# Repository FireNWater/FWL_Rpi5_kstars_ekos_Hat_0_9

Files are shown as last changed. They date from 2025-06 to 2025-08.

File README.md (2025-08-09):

# Raspberry Pi Hat for AstroArch Version 0.9

This repository is for a Raspberry Pi Hat that provides various hardware control functions for Astrophotography equipment. 

Currently this repository only contains the KiCAD files, but I will add more photos and instructions to build your own as I progress.

Here is the link to order PCBs at OshPark:  https://oshpark.com/shared_projects/S5zMuqNM

This is the link to DigiKey Parts List: https://www.digikey.com/en/mylists/list/DTLNYIF8ZV

The DigiKey list includes 10% attrition, so depending on how good you think you are you can save a bit of money there.

The files in the "Linux Software" folder are system files and aliases to help you control the various functions of the hat.  The systemd files are written so that all of the DC power ports and Dew Heater ports turn on once the Raspberry Pi has completed its boot up.  The udev rules will allow you to control the Rpi GPIO ports from the terminal without using sudo.  The aliases, are shortcuts to turning the DC power ports and Dew Heaters on and off from a terminal.

The "libgpiod" package must be installed in order to control the GPIO pins from the command line.  To install in Arch Linux type: "sudo pacman -S libgpiod" at the command line.

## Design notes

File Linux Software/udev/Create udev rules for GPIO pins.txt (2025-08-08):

https://wiki.gentoo.org/wiki/User:Brushdemon/Raspberry_Pi_GPIO

https://github.com/RPi-Distro/raspberrypi-sys-mods/blob/bookworm/etc.armhf/udev/rules.d/99-com.rules

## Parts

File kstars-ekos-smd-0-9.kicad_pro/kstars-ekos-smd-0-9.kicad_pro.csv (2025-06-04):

Reference | Value | Datasheet | Footprint | Qty | DNP
C1 | 10uF | ~ | Capacitor_SMD:C_0805_2012Metric | 1
C2,C2-1,C2-2 | 22uF | ~ | Capacitor_SMD:C_0805_2012Metric | 3
C3 | 100nF | ~ | Capacitor_SMD:C_0805_2012Metric | 1
C4 | 100pF | ~ | Capacitor_SMD:C_0805_2012Metric | 1
C5 | 2.7nF | ~ | Capacitor_SMD:C_0805_2012Metric | 1
C6 | 33pF | ~ | Capacitor_SMD:C_0805_2012Metric | 1
C11,C12,C13,C14,C15,C16 | ~ |  | Anderson Power Pole:APP 45A Vertical Contact | 6
Css1 | 10nF | ~ | Capacitor_SMD:C_0805_2012Metric | 1
F1 | Polyfuse - 6A | ~ | Fuse:Fuse_2920_7451Metric | 1
J1 | Raspberry_Pi_2_3 | https://www.raspberrypi.org/documentation/hardware/raspberrypi/schematics/rpi_SCH_3bplus_1p0_reduced.pdf | Raspberry Pi Hat Parts:Raspberry_Pi_40_Pin_Header_With_Lands | 1
J2,J3 | Conn_01x04 | ~ | Connector_PinHeader_2.54mm:PinHeader_1x04_P2.54mm_Vertical | 2
L1 | 3.6uH |  | 4:THMC0503SP-4R7MG-D | 1
R1 | 115K | ~ | Resistor_SMD:R_0805_2012Metric | 1
R2 | 22.1K | ~ | Resistor_SMD:R_0805_2012Metric | 1
R3 | 560 Ohm | EXB-2HV100JV | Resistor Array:RES_EXB2HV | 1
R5 | 15.8K | ~ | Resistor_SMD:R_0805_2012Metric | 1
U1 | AP64501SP-13 | AP64501QSP-13 | AP64501QSP_13:SO-8EP_DIO | 1
U2,U3,U4,U5 | TLP3553ATP1_F | TLP3553ATP1_F | 4A Solid State Relay:SOIC_3553ATP1_F_TOS | 4
U6,U7 | TLP241ATP1_F | TLP241ATP1_F | 4A Solid State Relay:SOIC_3553ATP1_F_TOS | 2

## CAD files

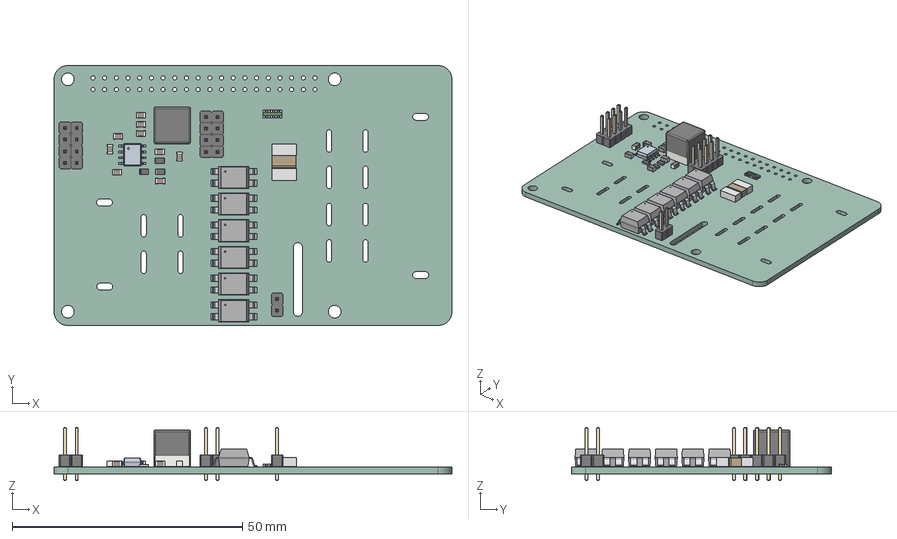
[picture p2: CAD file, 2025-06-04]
kstars-ekos-smd-0-9.kicad_pro/kstars-ekos-smd-0-9.kicad_pro.step
86.5 x 56.5 x 11.5 mm
741X163_CTS
PinHeader_1x02_P2.54mm_Vertical x 5
C_0805_2012Metric x 9
SOIC_3553A_TP1_F_TOS x 12
R_0805_2012Metric x 3
PinHeader_1x04_P2.54mm_Vertical x 2
L_Cenker_CKCS8080
FUSE_2920L11060_LTF
kstars-ekos-smd-0-9.kicad_pro 1.30.1
kstars-ekos-smd-0-9.kicad_pro_PCB

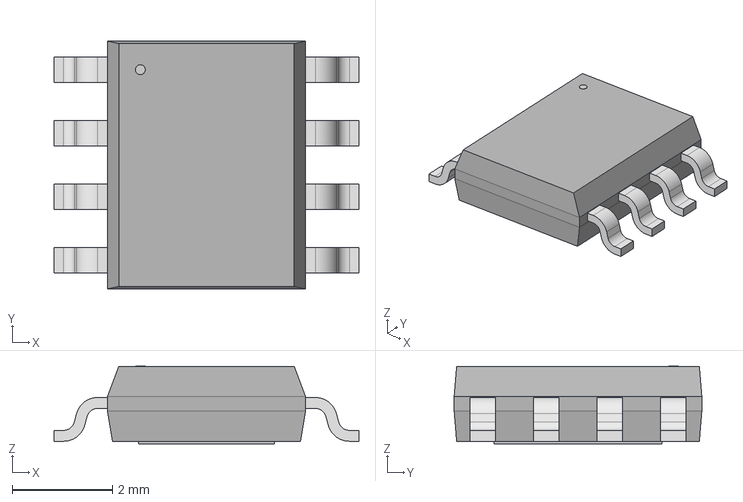
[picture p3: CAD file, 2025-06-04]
kstars-ekos-smd-0-9.kicad_pro/Project Library/AP64501-5V-DC-Buck/AP64501QSP_13/SO-8EP_DIO.step
6.10 x 4.95 x 1.55 mm

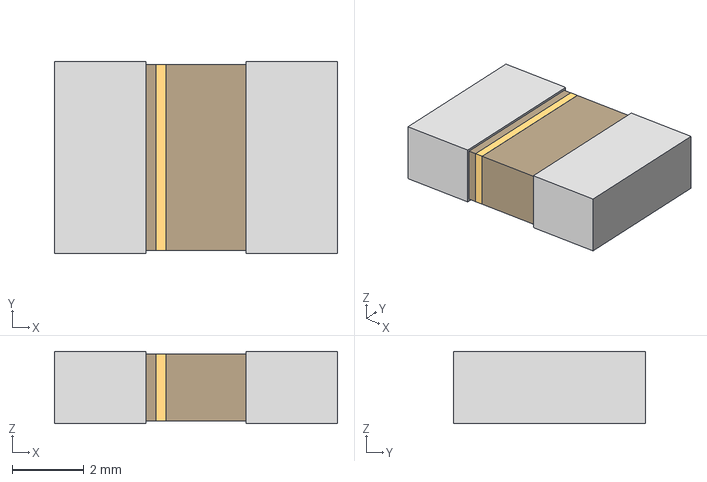
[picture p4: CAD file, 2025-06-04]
kstars-ekos-smd-0-9.kicad_pro/Project Library/PTC Resettable Fuse/ul_2920L110-60MR/FUSE_2920L11060_LTF.step
7.87 x 5.33 x 2.01 mm

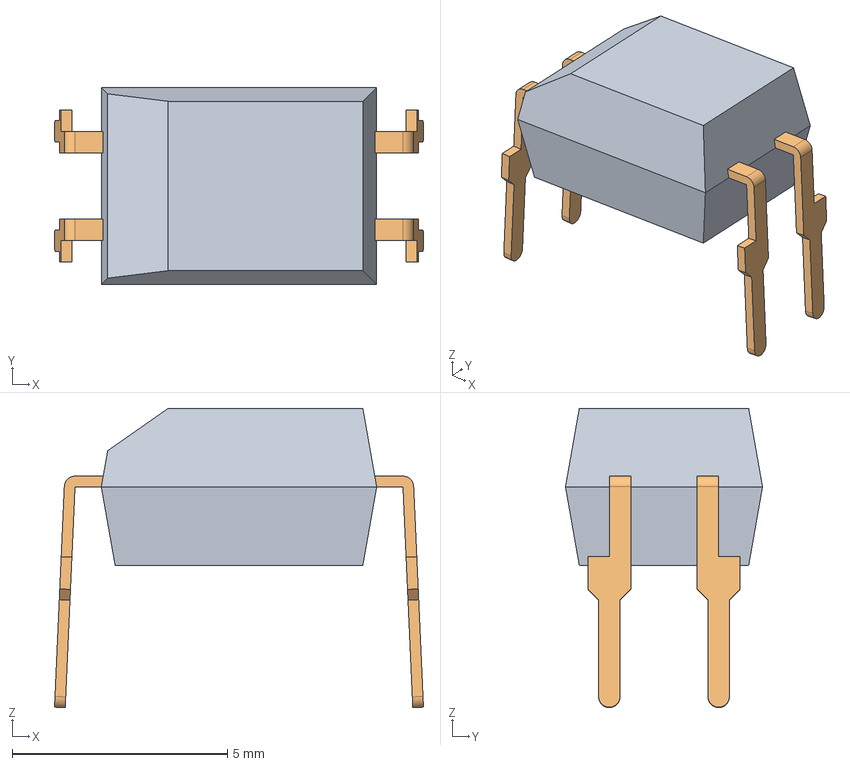
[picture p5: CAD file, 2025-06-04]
kstars-ekos-smd-0-9.kicad_pro/Project Library/TLP241A_TP1_F - 2A Solid State Relay/TLP241A_TP1_F/DIP4_90deg.stp
8.57 x 4.58 x 6.96 mm

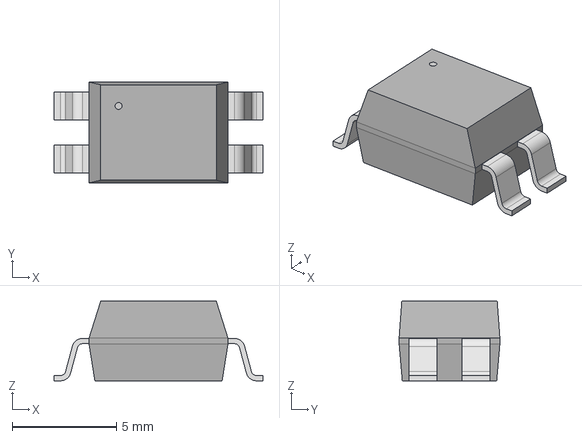
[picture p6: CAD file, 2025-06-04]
kstars-ekos-smd-0-9.kicad_pro/Project Library/TLP3553A_TP1_F - 4A Solid State Relay/TLP3553A_TP1_F/SOIC_3553A_TP1_F_TOS.step
10.0 x 4.83 x 3.81 mm

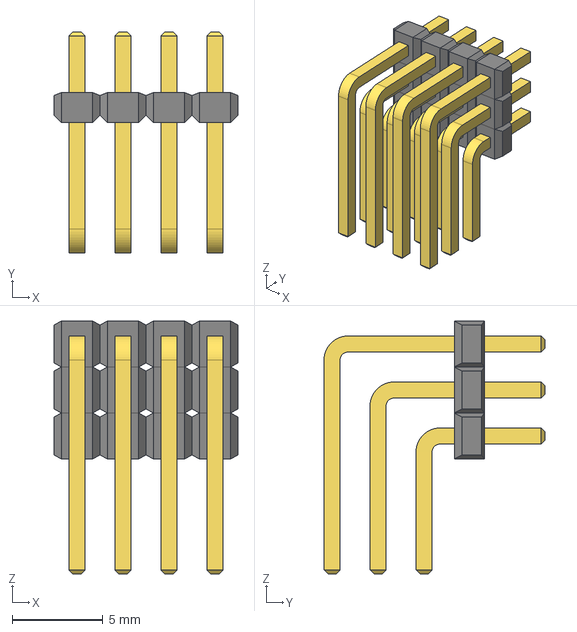
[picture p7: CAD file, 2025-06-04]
kstars-ekos-smd-0-9.kicad_pro/Project Library/TSW_104_08_G_T_RA/KiCADv6/TSW-104-08-T-T-RA_SAI.step
10.2 x 12.2 x 14.0 mm

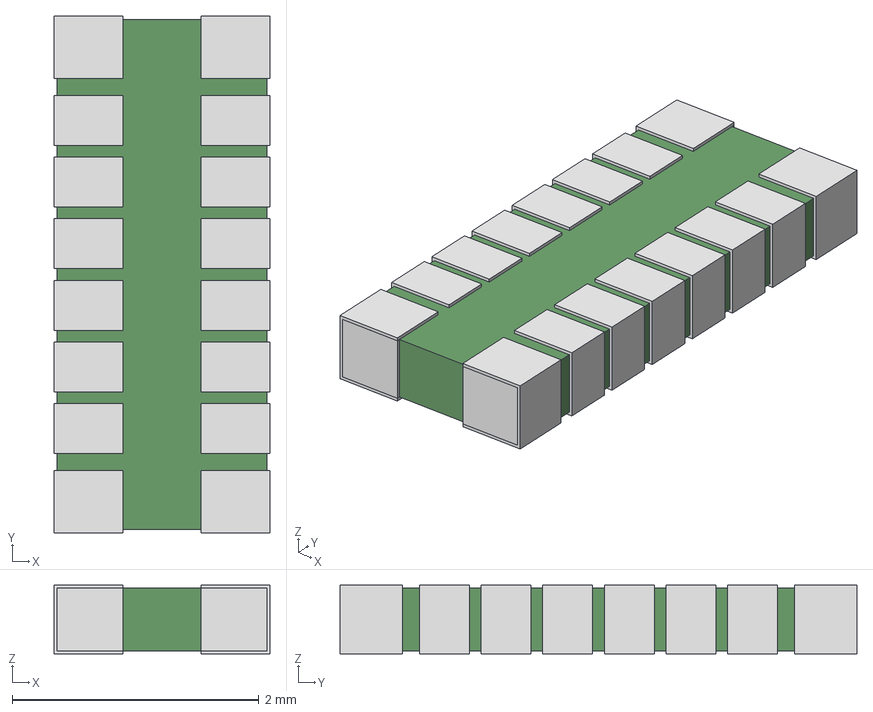
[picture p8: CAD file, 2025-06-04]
kstars-ekos-smd-0-9.kicad_pro/Project Library/ul_EXB-2HV100JV - Resistor Array/ul_741X163102JP/741X163_CTS.step
1.75 x 4.19 x 0.559 mm

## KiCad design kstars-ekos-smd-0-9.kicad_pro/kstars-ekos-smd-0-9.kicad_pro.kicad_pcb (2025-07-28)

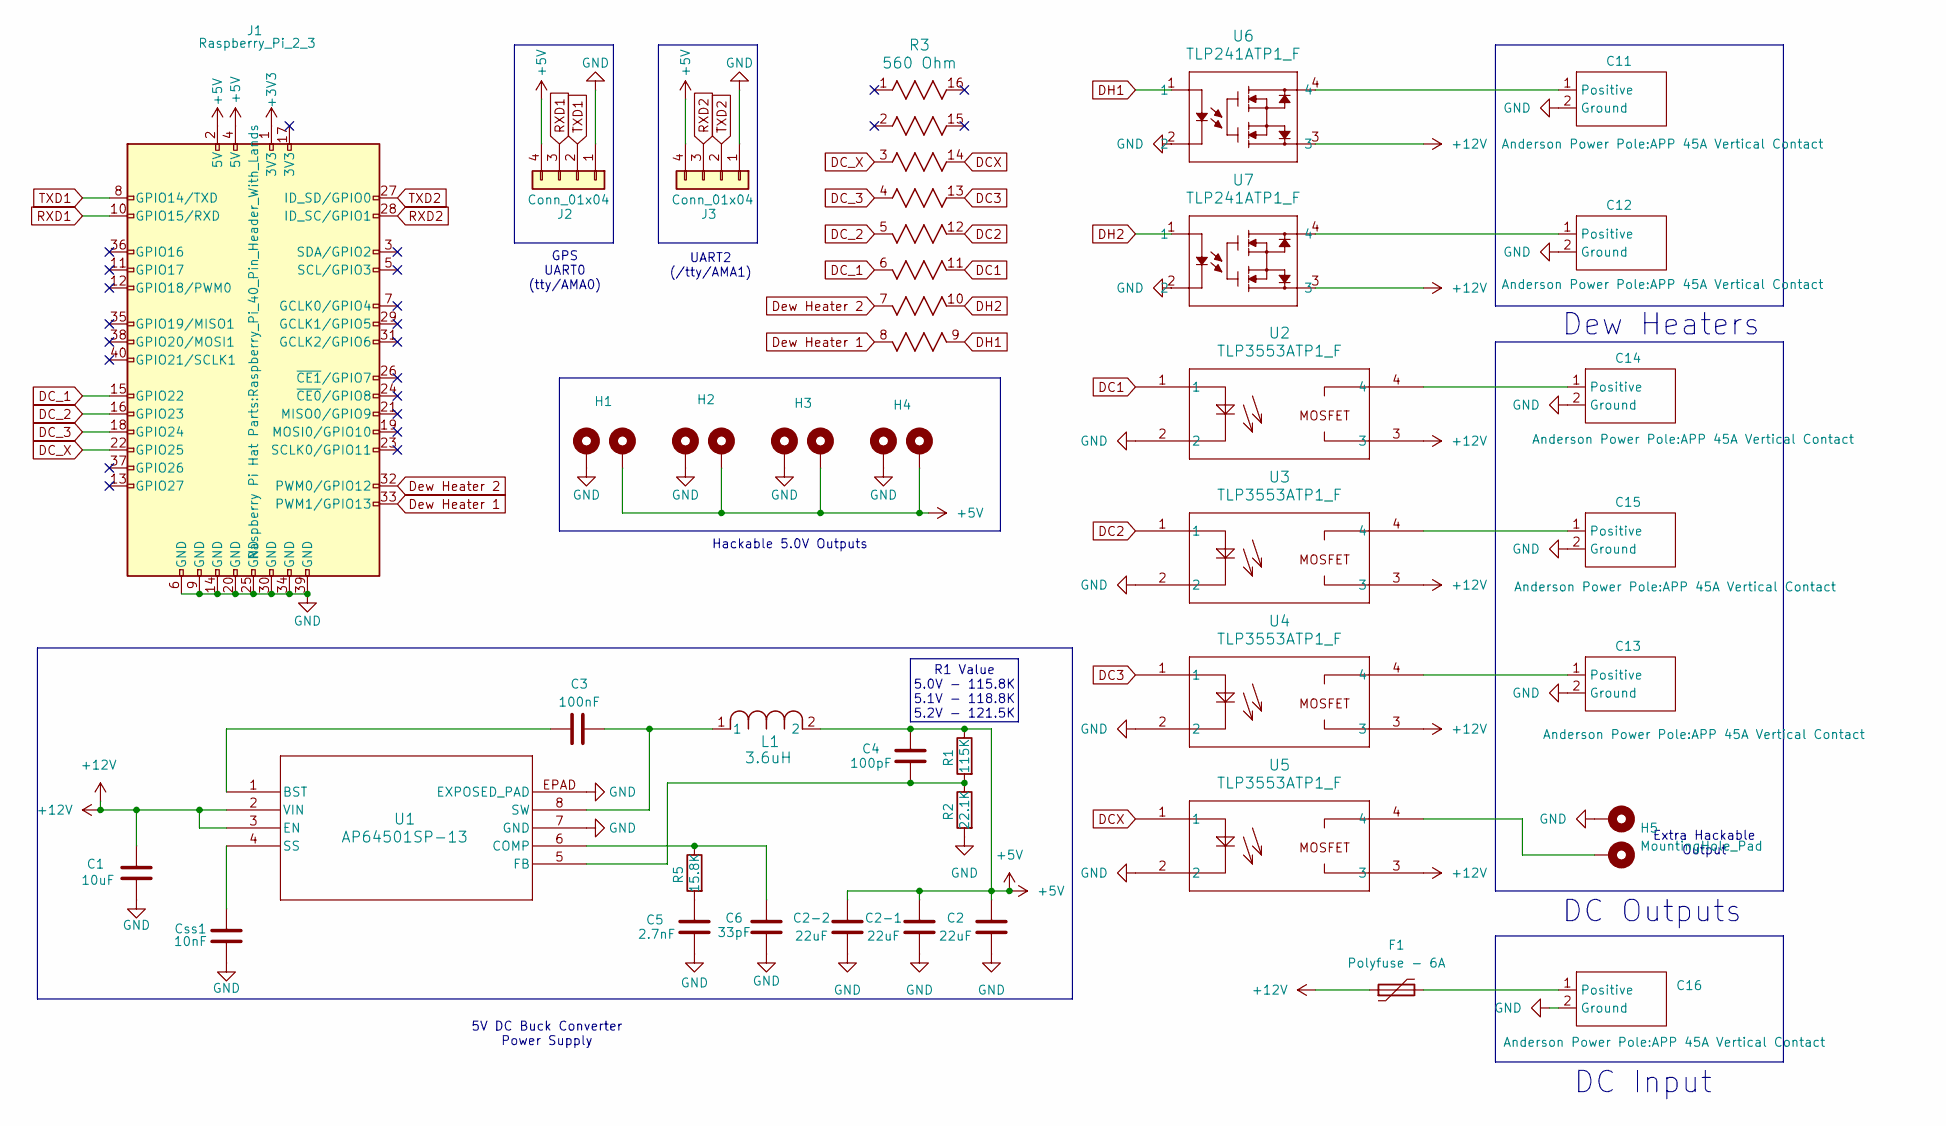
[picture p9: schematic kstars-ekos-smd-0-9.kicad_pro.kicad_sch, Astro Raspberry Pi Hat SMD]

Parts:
C1: 10uF; C_0805_2012Metric
C2, C2-1, C2-2: 22uF; C_0805_2012Metric
C3: 100nF; C_0805_2012Metric
C4: 100pF; C_0805_2012Metric
C5: 2.7nF; C_0805_2012Metric
C6: 33pF; C_0805_2012Metric
C11, C12, C13, C14, C15, C16: APP 45A Vertical Contact
Css1: 10nF; C_0805_2012Metric
F1: Polyfuse - 6A; Fuse_2920_7451Metric
H1, H2, H3, H4, H5: MountingHole_Pad; PinHeader_1x02_P2.54mm_Vertical
J1: Raspberry_Pi_2_3; Raspberry_Pi_40_Pin_Header_With_Lands
J2, J3: Conn_01x04; PinHeader_1x04_P2.54mm_Vertical
L1: 3.6uH; L_Cenker_CKCS8080
R1: 115K; R_0805_2012Metric
R2: 22.1K; R_0805_2012Metric
R3: 560 Ohm; RES_EXB2HV
R5: 15.8K; R_0805_2012Metric
U1: AP64501SP-13; SO-8EP_DIO
U2, U3, U4, U5: TLP3553ATP1_F; SOIC_3553ATP1_F_TOS
U6, U7: TLP241ATP1_F; SOIC_3553ATP1_F_TOS

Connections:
+3V3: J1.1 (3V3)
+5V: C2.2, C2-1.2, C2-2.2, C4.1, H1.2, H2.2, H3.2, H4.2, J1.2 (5V), J1.4 (5V), J2.4, J3.4, L1.2, R1.2
+12V: C1.2, F1.1, U1.2 (VIN), U1.3 (EN), U2.3, U3.3, U4.3, U5.3, U6.3, U7.3
DC1: R3.11, U2.1
DC2: R3.12, U3.1
DC3: R3.13, U4.1
DCX: R3.14, U5.1
DC_1: J1.15 (GPIO22), R3.6
DC_2: J1.16 (GPIO23), R3.5
DC_3: J1.18 (GPIO24), R3.4
DC_X: J1.22 (GPIO25), R3.3
DH1: R3.9, U6.1
DH2: R3.10, U7.1
Dew Heater 1: J1.33 (PWM1/GPIO13), R3.8
Dew Heater 2: J1.32 (PWM0/GPIO12), R3.7
GND: C1.1, C2.1, C2-1.1, C2-2.1, C5.2, C6.2, C11.2 (Ground), C12.2 (Ground), C13.2 (Ground), C14.2 (Ground), C15.2 (Ground), C16.2 (Ground), Css1.2, H1.1, H2.1, H3.1, H4.1, H5.1, J1.6 (GND), J1.9 (GND), J1.14 (GND), J1.20 (GND), J1.25 (GND), J1.30 (GND), J1.34 (GND), J1.39 (GND), J2.1, J3.1, R2.1, U1.7 (GND), U1.EPAD (EXPOSED_PAD), U2.2, U3.2, U4.2, U5.2, U6.2, U7.2
unnamed: C5.1, R5.1
unnamed: C11.1 (Positive), U6.4
unnamed: C12.1 (Positive), U7.4
unnamed: C13.1 (Positive), U4.4
unnamed: C14.1 (Positive), U2.4
unnamed: C15.1 (Positive), U3.4
unnamed: C16.1 (Positive), F1.2
unnamed: H5.2, U5.4
unnamed: C3.1, U1.1 (BST)
unnamed: C6.1, R5.2, U1.6 (COMP)
unnamed: C4.2, R1.1, R2.2, U1.5 (FB)
unnamed: Css1.1, U1.4 (SS)
unnamed: C3.2, L1.1, U1.8 (SW)
RXD1: J1.10 (GPIO15/RXD), J2.3
RXD2: J1.28 (ID_SC/GPIO1), J3.3
TXD1: J1.8 (GPIO14/TXD), J2.2
TXD2: J1.27 (ID_SD/GPIO0), J3.2

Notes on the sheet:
GPS UART0 (tty/AMA0)
5V DC Buck Converter Power Supply
UART2 (/tty/AMA1)
R1 Value 5.0V - 115.8K 5.1V - 118.8K 5.2V - 121.5K
Dew Heaters
Extra Hackable Output
DC Outputs
DC Input
Hackable 5.0V Outputs

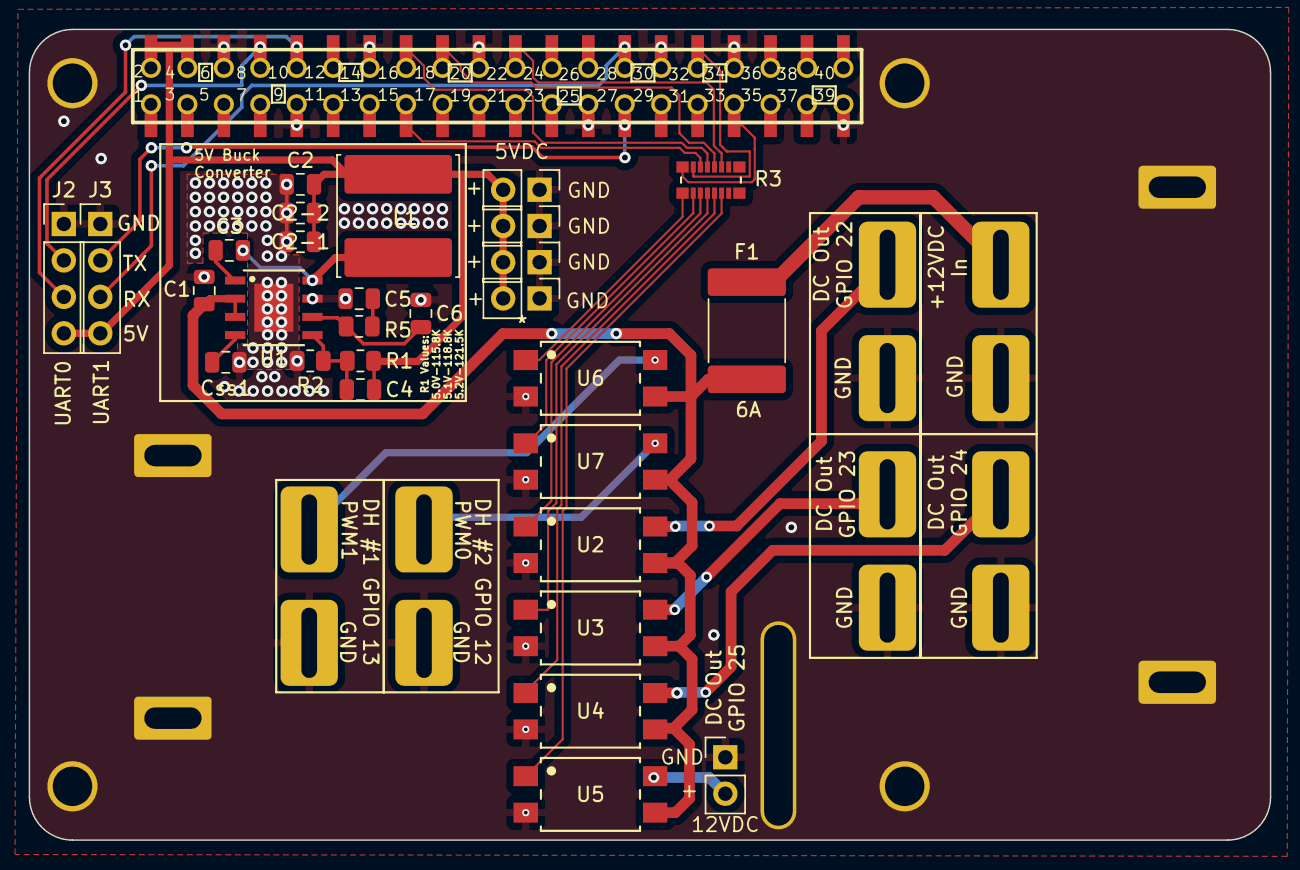
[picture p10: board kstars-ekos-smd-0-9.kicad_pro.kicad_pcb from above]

Board: 2 copper layers, 86.5 x 56.5 mm, 36 parts (0 on the bottom side), 32 nets.

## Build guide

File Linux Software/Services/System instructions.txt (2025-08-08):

Both files saved to:

/etc/systemd/system/

Then reboot

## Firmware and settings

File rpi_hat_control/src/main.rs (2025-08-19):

//pub mod pin_funcs;
pub mod menus;

use std::error::Error;
use rpi_pal::gpio::Gpio;
//use rpi_pal::system::DeviceInfo;  // TODO Add an item to "HatItem" struct showing which version Rpi is used

pub struct HatItem {
    pub pin_0_status: bool,
    pub pin_1_status: bool,
    pub pin_2_status: bool,
    pub pin_x_status: bool,
    pub dh_1_duty: f64,
    pub dh_2_duty: f64,
    pub gps_coord: String,
    pub temp: f32,
    pub humidity: f32,
    pub dew_point: f32,
    pub exit: bool,
}

fn main()-> Result<(), Box<dyn Error>>  {

// set initial pin statuses
let mut hat_status = HatItem { 
                                pin_0_status: true,
                                pin_1_status: true,
                                pin_2_status: true,
                                pin_x_status: true,
                                dh_1_duty: 50.0,
                                dh_2_duty: 50.0,
                                gps_coord: String::from("Placeholder Coord"),
                                temp: 25.5,
                                humidity: 20.5,
                                dew_point: 0.0,
                                exit: false,
                                };

// Initialize the GPIO pins and set them all for output . . . TODO Make an "enum" for all the pins

let gpio = Gpio::new()?;
let mut dc_port_1 = gpio.get(22)?.into_output();
let mut dc_port_2 = gpio.get(23)?.into_output();
let mut dc_port_3 = gpio.get(24)?.into_output();
let mut dc_port_x = gpio.get(25)?.into_output();
let mut dh_pin_1 = gpio.get(12)?.into_output();
let mut dh_pin_2 = gpio.get(13)?.into_output();

// Let's start by turning everything on . . . TODO check an "init" file for . .

dc_port_1.set_high();
dc_port_2.set_high();
dc_port_3.set_high();
dc_port_x.set_high();
dh_pin_1.set_pwm_frequency(10.0, hat_status.dh_1_duty)?;
dh_pin_2.set_pwm_frequency(10.0, hat_status.dh_2_duty)?;

// Begin Main loop that keeps going until the "exit" variable is set to true

loop {

    menus::menus::draw_menu(&mut hat_status);

    if hat_status.pin_0_status == true {
        dc_port_1.set_high();
    } else {
        dc_port_1.set_low();
    }

    if hat_status.pin_1_status == true {
        dc_port_2.set_high();
    } else {
        dc_port_2.set_low();
    }

    if hat_status.pin_2_status == true {
        dc_port_3.set_high();
    } else {
        dc_port_3.set_low();
    }

    if hat_status.pin_x_status == true {
        dc_port_x.set_high();
    } else {
        dc_port_x.set_low();
    }

    dh_pin_1.set_pwm_frequency(10.0, hat_status.dh_1_duty/100.0)?;
    dh_pin_2.set_pwm_frequency(10.0, hat_status.dh_2_duty/100.0)?;

    hat_status.dew_point = menus::menus::calculate_dew_point(hat_status.temp, hat_status.humidity);

    if hat_status.exit == true {break};

}

Ok(())
}

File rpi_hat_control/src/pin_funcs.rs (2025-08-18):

// pub mod pin_funcs {

// use rpi_pal::gpio::Gpio;
// //use rpi_pal::system::DeviceInfo;



//     pub fn all_dc_pins_on() {

//         let gpio_pins = [22, 23, 24, 25];   // The LED pins on the Rpi Hat

//         for led_pin in gpio_pins {
//             let mut pin = Gpio::new().get(led_pin).into_output()?;
//             pin.set_high();
//             }
//     }

//     pub fn all_dh_pins_on(){

//         let gpio_pins = [12, 13];   // The dew heater LED pins on the Rpi Hat

//         for led_pin in gpio_pins {
//             let mut pin = Gpio::new().get(led_pin).into_output();
//             pin.set_high();
//             }  
//     }

// }

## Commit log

2025-06-06 Final design submitted to fab.
    [kstars-ekos-smd-0-9.kicad_pro.kicad_pcb, kstars-ekos-smd-0-9.kicad_pro.kicad_sch]
2025-06-06 Corrected hole locations. Final upload to fab.
    [kstars-ekos-smd-0-9.kicad_pro.kicad_pcb]
2025-07-08 Updated 40-pin numbering silkscreen.
    [kstars-ekos-smd-0-9.kicad_pro.kicad_pcb, kstars-ekos-smd-0-9.kicad_pro.kicad_sch]
2025-07-10 Update README.md
    Added PCB and DigiKey parts list.
2025-07-28 Fixed GPIO16 trace . .
    [kstars-ekos-smd-0-9.kicad_pro.kicad_pcb]
2025-07-28 Connected GPIO 16 trace . .
2025-07-28 Fixed GPIO 16 trace
2025-07-28 Update README.md
    Updated PCB design.
